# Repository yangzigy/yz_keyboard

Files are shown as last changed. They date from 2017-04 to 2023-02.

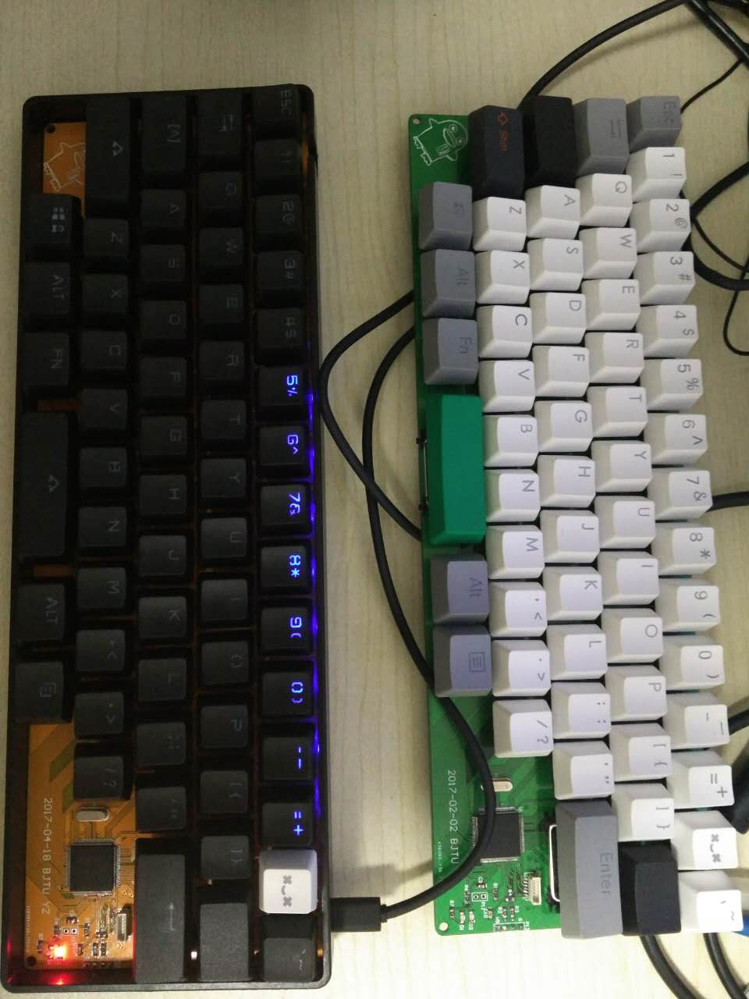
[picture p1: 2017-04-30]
pictures/1.jpg

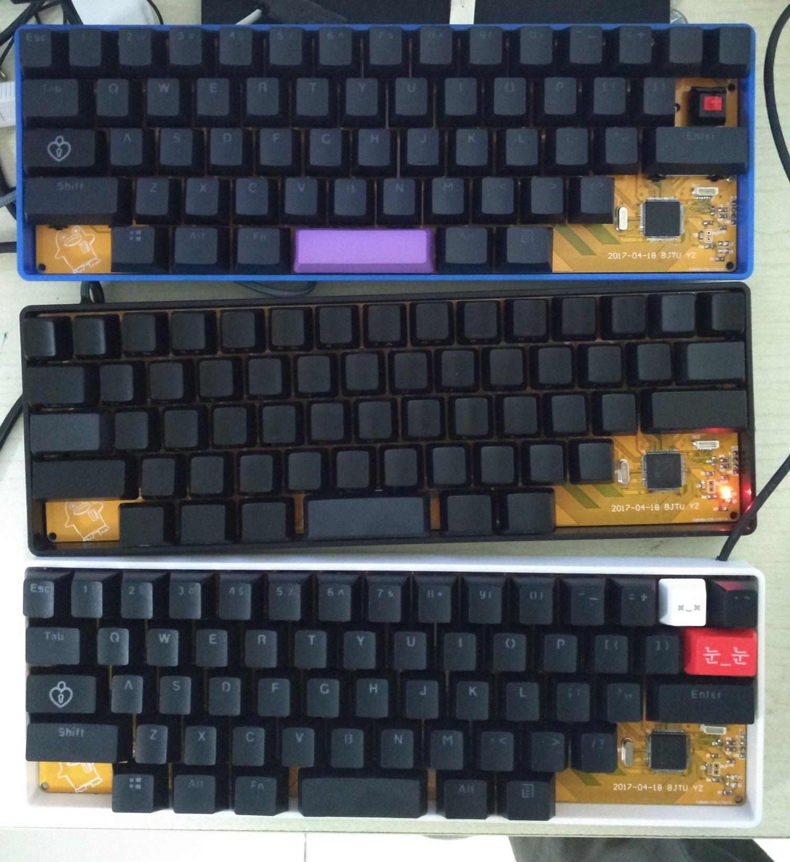
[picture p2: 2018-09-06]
pictures/IMG_20170524_213813_HHT.jpg

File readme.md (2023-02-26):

yz_keyboard
========

diy机械键盘，类似HHKB的布局，修改fn的位置，增加功能组合键定义，并加入鼠标功能。可实现动态led图案。  
  
说明地址：https://www.cnblogs.com/yangzifb/p/11485313.html
**设计思想：**  
1. 优先使用大拇指完成任务，实现组合键  
2. 减轻小拇指负担，将Ctrl移动到caplock处，取消caplock  
3. 方向键使用vim风格，home end pageup pagedown也使用hjkl实现  
4. 使用键盘模拟鼠标，用于连贯动作，减少键鼠切换，主要鼠标操作仍通过实体鼠标实现  
5. 缩小键盘尺寸，降低空间占用，减少手的移动范围  
6. 使用组合键并通过按键时长实现光标鼠标移动以及滚屏的连续控制，所以需要无段落感的轴  
7. 使用力量小的轴体以减缓手部疲劳。所以主要使用红轴  
8. 使用消音胶垫，进一步让感觉变软、变轻，降低噪音  
**实现参考：** http://tieba.baidu.com/p/4592747695  
后期可以考虑加入的功能：  
  1. 录制宏  
  2. 通过统计按键风格做一些智能动作,例如操作者识别，操作者工作状态、工作类别统计  
使用stm32f103vbt6，驱动键盘扫描、led和USB通信，没有使用固件库。  

## 设计  
### 按键设计  
仿HHKB的设计，使用59键，通过fn键复用按键。将fn位置放在左手大拇指处  
app键也作为fn使用，方便单手操作。只有APP键单独按下或无有效组合时用作APP键。  
复用按键：(失去所有复用按键的组合功能)  
1. F1~F12: 通过第一排按键实现  
2. del: 通过backspace和~实现,其中fn+~为shift+del  
3. 方向键： 通过vim风格的hjkl键实现  
4. home、end、pgup、pgdn：fn+a+hjkl(失去a+上下左右功能)  
5. home、end：fn+< > 方便单手操作  
6. insert、prtscren：fn+i,fn+p  
7. 上一级（alt+up）: fn+u  
8. 鼠标上下左右滚轮：fn+s+hjklnm(失去s+上下左右功能)  
9. 鼠标大幅上下左右：fn+a+s+hjklnm  
10. 鼠标按键：fn+dfgnm：左键中键右键,滚轮  
11. 鼠标拖动：fn+dfg+hjklnm  
12. 鼠标大幅拖动：fn+a+dfg+hjklnm  
### 布局  
使用键位编辑网站Keyboard-layout-editor编辑键盘的布局：http://www.keyboard-layout-editor.com/  
使用定位板生成网站http://builder.swillkb.com/  生成dxf  
将生成的文件导入Altium designer后，作为机械层辅助布局  

## 硬件实现  
### 电路部分  
为了实现全键任意组合，单片机的每一个引脚连接一个按键，单独进行扫描。  
通过传感引脚控制led的亮度，led设在按键上拉电阻后，成为上拉回路中的一部分。按键按下时，led最大亮度。按键松开时，单片机控制引脚为输出模式，低电平亮灯；设置为输入上拉模式时，灯灭。通过占空比实现亮度调节。  
扫描和灯的控制共用0.5ms的时隙，10ms为一组，每个时间组首先扫描按键，扫描完成后按照灯的亮度设定设置引脚是否需要输出。10ms后重新设置为输入模式扫描按键。所以按键扫描频率为100Hz，led的PWM频率为100Hz，占空比为20档。  
USB需申请500mA电流，使用100mA时，键盘容易掉。  
### 焊接  
led使用压降2~3V的高亮led，限流电阻1K，由MCU引脚直接驱动，驱动电流约1ma，全亮时MCU电流在可承载范围内，且1ma的驱动电流已经足够亮了。  
usb预留了miniUSB接口，但实际焊接时，由于线长吃力，容易掉。所以改成通过焊接USB线，或焊接miniUSB转接板的方式出线。  
### 键帽/外壳  
外壳使用GH60塑料外壳；  
卫星轴使用PCB卫星轴，3个X2的；  
键帽为一套标准键帽，其中右shift键安装在空格位置（可购买无刻2.75X R1），ctrl键购买无刻1.75X R2，反斜杠键购买无刻1X R4，退格键购买无刻1.5X R3  
## 程序结构  
### 文件组织  
<pre>
|~f103vbt6/			单片机程序
| |~app/				应用代码
| | |-key.c					按键扫描和定义文件
| | |-key.h
| | |-led.c					led与图形定义
| | `-led.h
| |+obj/				编译中间文件
| |~src/				单片机基础源文件
| | |-cmd.c
| | |-cmd.h
| | |-main.c
| | |-main.h
| | |-queue.c
| | `-queue.h
| |~sys/				单片机系统源文件
| | |-core_cm3.h
| | |-core_cmFunc.h
| | |-core_cmInstr.h
| | |-startup_stm32f10x_hd.s
| | |-stm32f10x.h [RO]
| | |-stm32f1_sys.c
| | `-stm32f1_sys.h
| |~hal/				硬件驱动
| | |-f1_uart.c
| | |-f1_uart.h			串口驱动文件
| | |-f1_usb.c
| | |-f1_usb.h			usb寄存器访问工具
| | |-usb_core.c
| | |-usb_core.h		usb枚举流程
| | |-usb_kb_m.c
| | `-usb_kb_m.h		usb键盘、鼠标描述符和协议实现
| |-JLinkSettings.ini
| |-keilkill.bat*
| |-test.uvoptx
| `-test.uvprojx
|+参考/				本项目的参考资料
|+pictures/			本项目过程照片
|+电路/				电路设计
|+电路库/			电路库文件
|-.gitignore
|-keyboard-layout.json	键盘的布局设计
|-readme.md			说明文件
|-效果.JPG			设计效果图
`-生成的CAD图.dxf	生成的键盘布局图，用于PCB布局
</pre>  

### MCU系统部分  
不使用stm32固件库，而是将MCU相关的宏定义、必须的函数集中在sys/stm32f1_sys.c .h文件对中，引用stm32f10x.h、core_cm3.h等少数文件作为单片机系统配置。  
在stm32f1_sys模块中定义MGPIO_TypeDef，代替原来固件库中的GPIO定义。在MGPIO_TypeDef中使用位段的方式定义控制寄存器，代替原来的通过函数配置GPIO。  
使用事件驱动方式实现并发，定义SYS_task变量用于存储系统中待执行的任务，其中每一bit代表一个任务需要执行。定义了START_TASK宏，用于启动一个任务（将代表此任务的bit置一）  
程序入口为main.c文件，main函数中首先配置系统时钟、周期中断、调试串口、调试指令模块，然后初始化USB和键盘模块，最后进入主循环。  
系统周期中断频率为2kHz，调试串口115200bps，系统主频72MHz。  
系统中定义了SYS_time变量作为系统时钟计数器，可以通过对此变量的求余，实现分频。  
在主循环中，不断扫描是否有任务需要执行，若有任务，则首先清除任务标志位，然后再执行任务。若先执行任务再清标志位，会导致在任务执行过程中产生的任务无法执行。  
在主循环中通过SYS_idle变量统计CPU占用，原理是每隔100ms就在定时中断中更新SYS_idle_dis变量，并清零SYS_idle变量。也就是说，SYS_idle在100ms内被主循环一直累加，100ms后被周期读取，得到的计数值是主循环的循环次数。在0负荷状态下，100ms内主循环运行约162000次，而系统带负载时，用于轮询主循环的时间线性降低，以比例计算出CPU占用率。所以在主循环中写了for(i=0;i<1620;i++)，让SYS_idle变量的值在100ms时大约为100，则带负载时输出SYS_idle变量的值大约就是CPU空闲百分比。  

### 串口调试指令  
使用USart1作为调试串口，与SWD调试线使用同一接口引出。用此串口实现一个简易的命令行（shell），实现代码为src/cmd.c .h文件对。cmd模块中，接收到的串口数据判断是否为回车换行，若是，则将缓冲中的文本作为指令处理，若不是，则给串口回显，并压入缓冲备用。这样，就可以通过超级终端等串口调试助手对单片机进行命令行控制。  
cmd模块的命令通过cmd_reg((CMD_LIST*)&bl_sys_cmd_list);函数实现注册，定义时将命令描述放在bl_sys_cmd_list数组中：  
"gk","display keybuf",cmdfun_getkeybuf,//显示发送缓冲
第一列为命令名称，第二列为命令的帮助信息，第三列为命令的执行函数。命令接受参数，以空格分割。命令执行函数的定义：  
void cmdfun_ledtest(char *para) //设置led亮度  
输入para为参数，通过sscanf函数读取  
串口通过统一的收发函数进行操作，收发均使用中断方式，均使用队列解耦。接收时接收中断和过载中断同时响应。  

### 按键扫描模块  
按键扫描的入口函数为key_poll，由主循环调用，频率2kHz。函数首先区分当前周期是扫描按键的周期还是led控制的周期，分别执行不同的功能。  
为了方便引脚的访问，提高运行效率，定义了一个数组：BUTTON_STATE keys[232]
keys数组是以按键号为索引的数组，存储了按键的GPIO的port、pin，状态、时间和亮度信息。由于键盘的按键号有很多保留，所以数组中有很多0，规定以port为0表示数组中的一个位置为保留。  
定义keys_index数组，用于高效的访问非零的按键数据。  
当进行按键扫描时，首先遍历所有非零按键位，将引脚配置为输入上拉模式。然后调用key_scan函数进行按键扫描，在此函数中调用check_press函数判断按键是否按下，并以一定的间隔时间防抖。key_scan函数在扫描完成后开始判断发送值，首先为特殊按键赋值，然后判断Fn组合键，然后判断正常按键。  
发送指令时，keyboard_send和mouse_send函数判断是否有变化，若无变化且鼠标速度为0，则不再发送。若以查询式一直发送键鼠数据，则在开机BIOS中无法通过键盘选择菜单。  
### led模块  
led模块定义了led数组const u8 ascii_index[256]，此数组作为索引，将按键的ascii值转换为按键扫描模块keys数组的索引（按键码）。  
led模块以led_poll函数为入口，调用具体图案函数执行，在图案函数中，设置图案数组，调用led_set_pattern函数进行led亮度赋值。图案数组为S_LED_LIGHT结构的数组，第一个域为按键的ascii表示，对于特殊按键的表示见ascii_index数组的注释，若为1，则为一个图形的结束。第二个域为亮度。若第一个域为1，则第二个域表示这个图形的持续时间。led_set_pattern函数只返回持续时间，延时由图案函数执行。延时的单位为led_poll的周期，100Hz。  
### usb部分  
#### 基本概念  
usb部分分3层：
1. 硬件设备访问（f1_usb.c）负责寄存器访问抽象，依赖usb逻辑层
2. usb逻辑层（usb_core.c）负责usb描述符等管理逻辑实现，不依赖其他层，具有通用性
3. 应用层（usb_kb_m.c）负责具体到本键盘应用的usb描述符实现，usb通信收发，依赖上述两层
usb通信的基本流程是host主动，从机纯被动，所以发送都是事先准备好数据到缓冲区，等host来取。每次传输完成后端点会自动设置为NAK状态，并给中断，让应用程序准备好下次传输。
每个端点有两个分组缓冲，一个收一个发。可位于缓冲区的任意位置，由缓冲区表描述收发缓存的地址和长度，缓冲区表也在缓冲区中。

所以usb的512字节缓冲区如何用是需要应用来设计的，一般从0开始是缓冲区表，依次描述各端点的缓冲区地址和长度。然后为每个缓存分配空间。

usb逻辑层实现描述符等初始化逻辑，由于端点0的通信需要发送的数据长度大于一包长度，所以在usb_core中做了状态机分包发送

#### 发送流程  
通过keyboard_send和mouse_send函数发送数据，只是将数据放在发送缓冲区中，等host来取。并没有实现批量数据的发送功能，如果需要实现任意数据的收发，需要在此做队列缓存

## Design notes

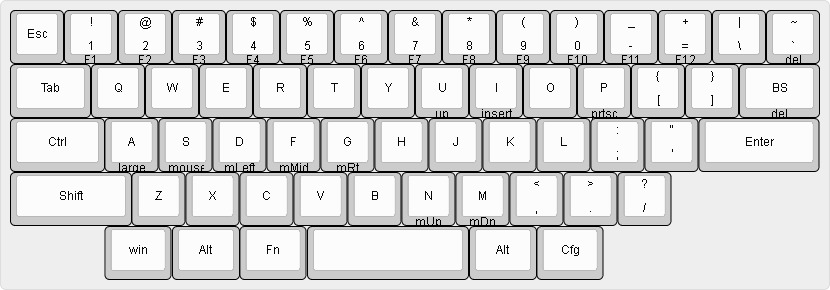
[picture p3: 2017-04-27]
效果.JPG

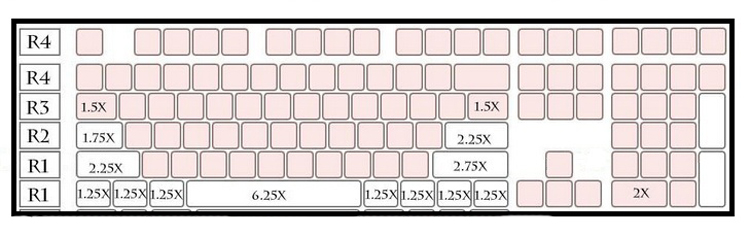
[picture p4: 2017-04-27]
参考/TB2KxndXZtnpuFjSZFvXXbcTpXa_!!134583372.jpg

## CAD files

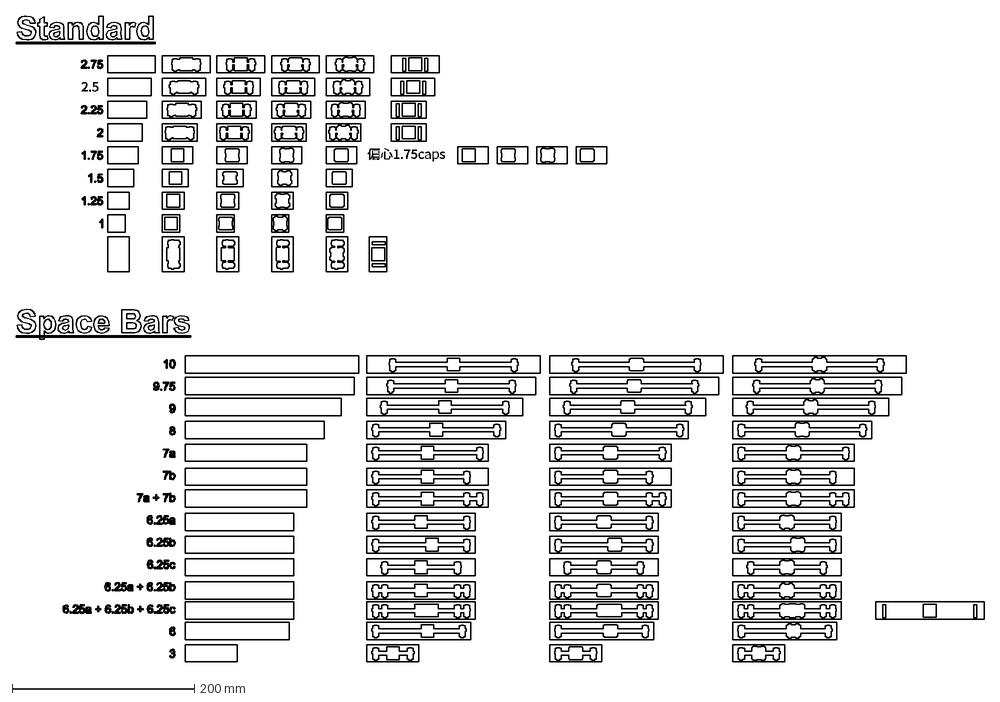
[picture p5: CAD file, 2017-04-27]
参考/键位表全.DXF
2.5
偏心1.75caps

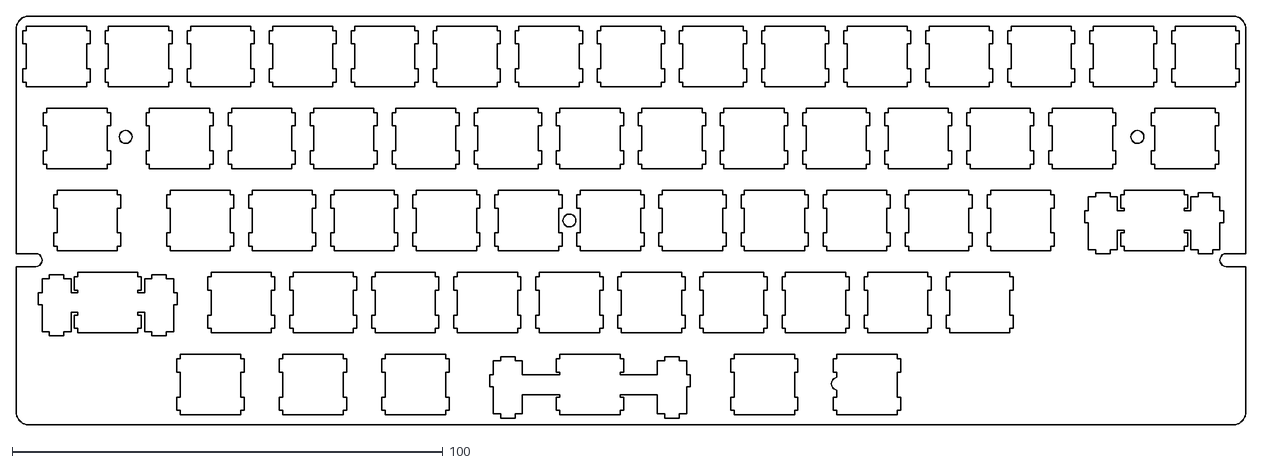
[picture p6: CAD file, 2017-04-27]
生成的CAD图.dxf
285.4 x 94.9

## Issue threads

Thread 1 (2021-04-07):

Boot Keyboard的问题

jerry-yuan, 2021-04-07:
老兄用STM32 USB-FS的Joystick改的键盘,在BIOS下好使么....

yangzigy, 2021-04-07:
我这个好使，键鼠一体，调工控板可以只插一个键盘

jerry-yuan, 2021-04-07:
我看了一下我改的键盘和你的键盘，报告描述符是一样的，但是我的在部分BIOS下键位都是乱的，另外在Linux下似乎也存在问题。😂

yangzigy, 2021-04-08:
只在BIOS乱吗？我这个之前调树莓派nanopi之类的板子没出过问题，x86的是uefi界面改Ubuntu，这几个场景都是一致的

yangzigy, 2021-04-08:
只在BIOS乱吗？我这个之前调树莓派、nanopi之类的板子，x86的uefi界面改Ubuntu，这几个场景都是一致的
有时候是某个键一直按下，或者发送数据中有未初始化的位导致错乱

jerry-yuan, 2021-04-08:
BIOS的话不是所有BIOS都键位乱,有些BIOS键位是乱的,有些BIOS就没事.

树莓派我没有尝试过是不是正常,x86的Ubuntu我试了几个了,有反应但是好像键盘布局全乱的.

至于某个键一直按下我的倒是没出现过....

jerry-yuan, 2021-04-10:
已经修好了，发现报告描述符还是有点不一样的，在后边6字节的键码上的LOGICAL_MINIUM设置成了1，导致键码全部往后错了一个。

所以但凡读了报告描述符的BIOS(e.g.Dell 2015年以后的BIOS)或者操作系统(e.g.Linux)全部出问题了，而没有实际从设备中读取报告描述符直接照着Boot Keyboard的报告描述符读数据的BIOS(e.g.老BIOS)和操作系统(e.g.Windows)都是正常的。

感谢老兄提供的信息。

Closed 2021-04-10.

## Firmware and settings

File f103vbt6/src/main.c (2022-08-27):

#include "f1_uart.h"
#include "cmd.h"
#include "key.h"
#include "usb_kb_m.h"

int get_que_data(u8 *p,Queue *q);
#define TASK_POOL_2K 2
u32 led_div=512-1; //led分频系数

void systime_initial(u32 frq)//输入为中断频率
{
	//输入频率默认HCLK/8=9MHz=9000000
	SysTick->LOAD=9000000/frq;
	SysTick->CTRL |= 2;//开中断
	SysTick->CTRL |= 1;
}
extern CMD_LIST bl_sys_cmd_list;
int main(void)
{
	Stm32_Clock_Init(9);//系统时钟,所有都必须在此函数后
	RCC->APB2ENR|=0x1ff;   //使能所有PORT口时钟
	systime_initial(2000);//Hz
	MGPIOD->CT13=GPIO_OUT_PP; //LED
	uart_initial(&uart1,115200);
	uart_initial(&uart2,115200);

	IO_putchar=uart1_putchar;
	cmd_ini();
	cmd_reg((CMD_LIST*)&bl_sys_cmd_list);
	//printf(HelloString);
	usb_ini();
	key_ini();
	while(1)
	{
		int i;
		for(i=0;i<1620;i++)
		{
			u8 tt;//队列实参
			if(uart1.que_rx.dlen>0) //这个只读不用锁
			{ 
				while(get_que_data(&tt,&(uart1.que_rx))==0)
				{
					cmd_fun(tt);
				}
			}
			if(SYS_task & TASK_POOL_2K) //2000Hz任务
			{
				SYS_task &= ~TASK_POOL_2K;
				key_poll();
				if(usb_stat==USB_ATTACHED) led_div=511; //加入USB连接指示
				else led_div=4095;
				if((SYS_time & led_div)==0) PDout(13)^=1; //LED分频后，让IO反转
			}
		}
		SYS_idle++;
	}
}
void SysTick_Handler(void) //2000Hz
{
	SYS_time++;
	START_TASK(TASK_POOL_2K);
	if(SYS_time%200==1)
	{
		SYS_idle_dis=(SYS_idle_dis+SYS_idle)/2;
		SYS_idle=0;
	}
}
int get_que_data(u8 *p,Queue *q)
{
	int rst=1;
	OS_CLOSE_INT;
	rst=Queue_get_1(p,q);
	OS_OPEN_INT;
	return rst;
}
//////////////////////////////////////////////////////////////////////////
//			指令
extern u8 keybuf[8];
void cmdfun_getkeybuf(char *para) //显示发送缓冲
{
	int i;
	for(i=0;i<sizeof(keybuf);i++)
	{
		printf("%02X ",keybuf[i]);
	}
	printf("\r\n");
}
extern u8 mousebuf[5]; //鼠标发送缓存
extern void mouse_send(u8 *buf);
void cmdfun_mousetest(char *para) //显示鼠标发送缓冲
{
	int i;
	mousebuf[0]=1;
	mousebuf[1] = (1<<0);
	mouse_send(mousebuf);
	for(i=0;i<sizeof(mousebuf);i++)
	{
		printf("%02X ",mousebuf[i]);
	}
	printf("\r\n");
}
void cmdfun_ledtest(char *para) //设置led亮度
{
	int b;
	char c;
	if(sscanf(para,"%c %d",&c,&b)==2)
	{
		extern const u8 ascii_index[256];
		keys[ascii_index[c]].led=b;
	}
}
static const CMD_STR blcmd_str[]=\
{
	"gk","display keybuf",cmdfun_getkeybuf,//显示发送缓冲
	"m", "mouse test",cmdfun_mousetest, //显示鼠标发送缓冲
	"led","led test",cmdfun_ledtest, //设置led亮度
};
CMD_LIST bl_sys_cmd_list={blcmd_str,sizeof(blcmd_str)/sizeof(CMD_STR),0};

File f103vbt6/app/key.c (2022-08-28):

#include "key.h"
#include "led.h"
#include "usb_kb_m.h"

int keys_per_sec=0; //每秒按键数
float keys_per_sec_f=0; //每秒按键数滤波结果
BUTTON_STATE keys[232]= //按键码为索引
{
	0,MGPIOD,9,0,0, //Fn
	0,0,0,0,0, //1
	0,0,0,0,0, //2
	0,0,0,0,0, //3
	0,MGPIOE, 9,0,0, //4 KEY_a
	0,MGPIOE,15,0,0, //5 KEY_b
	0,MGPIOB,11,0,0, //6 KEY_c
	0,MGPIOE, 7,0,0, //7 KEY_d
	0,MGPIOA, 1,0,0, //8 KEY_e
	0,MGPIOB, 1,0,0, //9 KEY_f
	0,MGPIOB, 0,0,0, //10 KEY_g
	0,MGPIOC, 5,0,0, //11 KEY_h
	0,MGPIOE, 6,0,0, //12 KEY_i
	0,MGPIOC, 4,0,0, //13 KEY_j
	0,MGPIOA, 7,0,0, //14 KEY_k
	0,MGPIOA, 6,0,0, //15 KEY_l
	0,MGPIOE,13,0,0, //16 KEY_m
	0,MGPIOE,14,0,0, //17 KEY_n
	0,MGPIOE, 5,0,0, //18 KEY_o
	0,MGPIOE, 4,0,0, //19 KEY_p
	0,MGPIOA, 3,0,0, //20 KEY_q
	0,MGPIOA, 0,0,0, //21 KEY_r
	0,MGPIOE, 8,0,0, //22 KEY_s
	0,MGPIOC, 3,0,0, //23 KEY_t
	0,MGPIOC, 1,0,0, //24 KEY_u
	0,MGPIOB,10,0,0, //25 KEY_v
	0,MGPIOA, 2,0,0, //26 KEY_w
	0,MGPIOB,12,0,0, //27 KEY_x
	0,MGPIOC, 2,0,0, //28 KEY_y
	0,MGPIOB,13,0,0, //29 KEY_z
	0,MGPIOE, 1,0,0, //30 KEY_1
	0,MGPIOE, 0,0,0, //31 KEY_2
	0,MGPIOB, 9,0,0, //32 KEY_3
	0,MGPIOB, 8,0,0, //33 KEY_4
	0,MGPIOB, 7,0,0, //34 KEY_5
	0,MGPIOB, 6,0,0, //35 KEY_6
	0,MGPIOB, 5,0,0, //36 KEY_7
	0,MGPIOD, 7,0,0, //37 KEY_8
	0,MGPIOD, 6,0,0, //38 KEY_9
	0,MGPIOD, 5,0,0, //39 KEY_0
	0,MGPIOC,12,0,0, //40 KEY_ENTER
	0,MGPIOE, 2,0,0, //41 KEY_ESCAPE
	0,MGPIOC,11,0,0, //42 KEY_BackSpace
	0,MGPIOA, 4,0,0, //43 KEY_Tab
	0,MGPIOD,10,0,0, //44 KEY_Space
	0,MGPIOD, 3,0,0, //45 KEY_Minus
	0,MGPIOD, 2,0,0, //46 KEY_Equal
	0,MGPIOD, 4,0,0, //47 KEY_Bracket1 [ and { 
	0,MGPIOD, 1,0,0, //48 KEY_Bracket2 ] and } 
	0,MGPIOD, 0,0,0, //49 KEY_BackSlash \ and | 
	//0,MGPIOC,10,0,0, //50 KEY_Wave ~
	0,0,0,0,0, //50 KEY_Wave ~
	0,MGPIOC, 0,0,0, //51 KEY_Semicolon ; and : 
	0,MGPIOE, 3,0,0, //52 KEY_Quotes ‘ and “ 
	0,MGPIOC,10,0,0, //53 e KEY_  KEY_Wave
	0,MGPIOE,12,0,0, //54 KEY_Comma , and < 
	0,MGPIOE,11,0,0, //55 KEY_StopPoint . and > 
	0,MGPIOA, 5,0,0, //56 KEY_QuestionMark / and ? 
	0,0,0,0,0, //57 KEY_Caps
	0,0,0,0,0, //58 KEY_F1
	0,0,0,0,0, //59 KEY_F2
	0,0,0,0,0, //60 KEY_F3
	0,0,0,0,0, //61 KEY_F4
	0,0,0,0,0, //62 KEY_F5
	0,0,0,0,0, //63 KEY_F6
	0,0,0,0,0, //64 KEY_F7
	0,0,0,0,0, //65 KEY_F8
	0,0,0,0,0, //66 KEY_F9
	0,0,0,0,0, //67 KEY_F10
	0,0,0,0,0, //68 KEY_F11
	0,0,0,0,0, //69 KEY_F12
	0,0,0,0,0, //70 KEY_PrintScree
	0,0,0,0,0, //71 KEY_Scroll
	0,0,0,0,0, //72 KEY_Pause
	0,0,0,0,0, //73 KEY_Insert
	0,0,0,0,0, //74 KEY_Home
	0,0,0,0,0, //75 KEY_PageUp
	0,0,0,0,0, //76 KEY_Delete
	0,0,0,0,0, //77 KEY_End
	0,0,0,0,0, //78 KEY_PageDown
	0,0,0,0,0, //79 KEY_RightArrow
	0,0,0,0,0, //80 KEY_LeftArrow
	0,0,0,0,0, //81 KEY_DownArrow
	0,0,0,0,0, //82 KEY_UpArrow
	0,0,0,0,0, //83 KEY_NumLock
	0,0,0,0,0, //84
	0,0,0,0,0, //85
	0,0,0,0,0, //86
	0,0,0,0,0, //87
	0,0,0,0,0, //88
	0,0,0,0,0, //89
	0,0,0,0,0, //90
	0,0,0,0,0, //91
	0,0,0,0,0, //92
	0,0,0,0,0, //93
	0,0,0,0,0, //94
	0,0,0,0,0, //95
	0,0,0,0,0, //96
	0,0,0,0,0, //97
	0,0,0,0,0, //98
	0,0,0,0,0, //99
	0,0,0,0,0, //100
	0,MGPIOD,12,0,0, //101 KEY_APP
	0,0,0,0,0, //102
	0,0,0,0,0, //103
	0,0,0,0,0, //104
	0,0,0,0,0, //105
	0,0,0,0,0, //106
	0,0,0,0,0, //107
	0,0,0,0,0, //108
	0,0,0,0,0, //109
	0,0,0,0,0, //110
	0,0,0,0,0, //111
	0,0,0,0,0, //112
	0,0,0,0,0, //113
	0,0,0,0,0, //114
	0,0,0,0,0, //115
	0,0,0,0,0, //116
	0,0,0,0,0, //117
	0,0,0,0,0, //118 KEY_cfg
	0,0,0,0,0, //119
	0,0,0,0,0, //120
	0,0,0,0,0, //121
	0,0,0,0,0, //122
	0,0,0,0,0, //123
	0,0,0,0,0, //124
	0,0,0,0,0, //125
	0,0,0,0,0, //126
	0,0,0,0,0, //127
	0,0,0,0,0, //128
	0,0,0,0,0, //129
	0,0,0,0,0, //130
	0,0,0,0,0, //131
	0,0,0,0,0, //132
	0,0,0,0,0, //133
	0,0,0,0,0, //134
	0,0,0,0,0, //135
	0,0,0,0,0, //136
	0,0,0,0,0, //137
	0,0,0,0,0, //138
	0,0,0,0,0, //139
	0,0,0,0,0, //140
	0,0,0,0,0, //141
	0,0,0,0,0, //142
	0,0,0,0,0, //143
	0,0,0,0,0, //144
	0,0,0,0,0, //145
	0,0,0,0,0, //146
	0,0,0,0,0, //147
	0,0,0,0,0, //148
	0,0,0,0,0, //149
	0,0,0,0,0, //150
	0,0,0,0,0, //151
	0,0,0,0,0, //152
	0,0,0,0,0, //153
	0,0,0,0,0, //154
	0,0,0,0,0, //155
	0,0,0,0,0, //156
	0,0,0,0,0, //157
	0,0,0,0,0, //158
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
	0,MGPIOE,10,0,0, //224 LeftControl
	0,MGPIOB,14,0,0, //225 LeftShift
	0,MGPIOD, 8,0,0, //226 LeftAlt
	0,MGPIOB,15,0,0, //227 LeftGUI
	0,0,0,0,0, //228 RightControl
	0,0,0,0,0, //229 RightShift
	0,MGPIOD,11,0,0, //230 RightAlt
	0,0,0,0,0, //231 RightGUI
};
u8 keys_index[232]; //keys数组0太多，用一个索引得到非零的
int keys_none0=0; //非零个数

void set_gpio(MGPIO_TypeDef *port,u8 pin,u32 type)
{
	switch(pin)
	{
	case 0: port->CT0=type; break;
	case 1: port->CT1=type; break;
	case 2: port->CT2=type; break;
	case 3: port->CT3=type; break;
	case 4: port->CT4=type; break;
	case 5: port->CT5=type; break;
	case 6: port->CT6=type; break;
	case 7: port->CT7=type; break;
	case 8: port->CT8=type; break;
	case 9: port->CT9=type; break;
	case 10: port->CT10=type; break;
	case 11: port->CT11=type; break;
	case 12: port->CT12=type; break;
	case 13: port->CT13=type; break;
	case 14: port->CT14=type; break;
	case 15: port->CT15=type; break;
	break;
	}
}
void key_ini(void)
{
	//认为时钟已经打开
	int i;
	for(i = 0; i < sizeof(keys)/sizeof(BUTTON_STATE); i++) //初始化非0索引,便于遍历
	{
		if(keys[i].port==0) continue;
		set_gpio(keys[i].port,keys[i].pin,GPIO_IN_PP);
		keys[i].port->BSRR=(1<<keys[i].pin); //输入上拉
		//初始化index
		keys_index[keys_none0]=i;
		keys_none0++;
	}
}
s8 mousebuf[5]={1,0,0,0,0}; //鼠标发送缓存
u8 keybuf[8]={0,0,0,0,0,0,0,0}; //按键发送缓存
int keybufp=2; //位置
void putkey(u32 key) //发现一个键按下
{
	if(keybufp==8) //若已经超过6个了
	{
		//发送0xffff;
		memset(keybuf,0xff,8);
		keybufp++;
		return ;
	}
	else if(keybufp>8)
	{
		return ;
	}
	keybuf[keybufp++]=key;
}
void check_press(BUTTON_STATE *bts) //判断按键是否按下
{
	if(bts->port==0)
	{
		return ;
	}
	if(!(bts->port->IDR & (1<<(bts->pin))))
	{
		bts->tick=SYS_time;
		bts->state=1;
	}
	else //若释放了
	{
		if (SYS_time-bts->tick>5) //并且tick值在5个以上
		{
			bts->state=0;
		}
	}
}
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

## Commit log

2017-04-27 整理后提交
    [KBV1.2.PcbDoc, KBV1.3.PcbDoc, KeyBoard.PcbLib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]
2017-04-30 修改了鼠标滚轮bug，修改了USB申请电流为500mA
2017-05-03 加入了USB连接状态，修改键盘发送规则为变化时发送，鼠标变化或速度非零时发送
2017-05-03 优化了鼠标滚轮
2017-05-05 让fn+~作为shift+del，在Windows下彻底删除文件
2017-05-06 修改了图形
2017-05-15 增加了APP键作为fn，单独按下时作为APP，方便单手操作
2017-05-30 修改了说明
2017-06-10 修改了串口源文件错误
2017-06-26 增加默认图案
    [PCB_Project1.PrjPCB]
2018-01-19 修改图案bug
    [KBV1.3.PcbDoc]
2018-07-30 修改图案
2018-09-04 修改图片
2018-09-06 加入焊接/键帽记录
2020-04-17 修改鼠标滚轮强度
2020-05-06 更新图片地址
2021-12-19 灯全亮，亮度2，轮番亮，防止MCU超载
2022-08-25 整理代码
2022-08-26 修改文件名
2022-09-03 完成usb库的重构
2022-09-03 修改说明
2023-02-26 整理usb库代码
